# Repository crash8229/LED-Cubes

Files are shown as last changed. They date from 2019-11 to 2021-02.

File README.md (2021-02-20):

# LED-Cubes
A repo to hold my LED cube related projects.

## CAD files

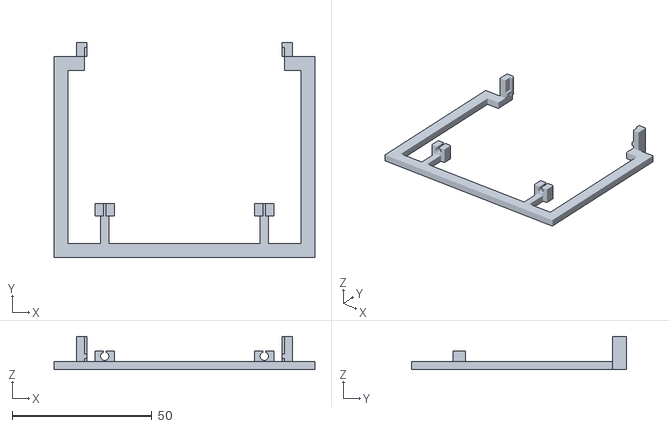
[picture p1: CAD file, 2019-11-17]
LED_Matrix_Jigs/LED_Matrix_Full_Assembly_Jig_Part_2_of_4.stl
93.5 x 77.0 x 12.0

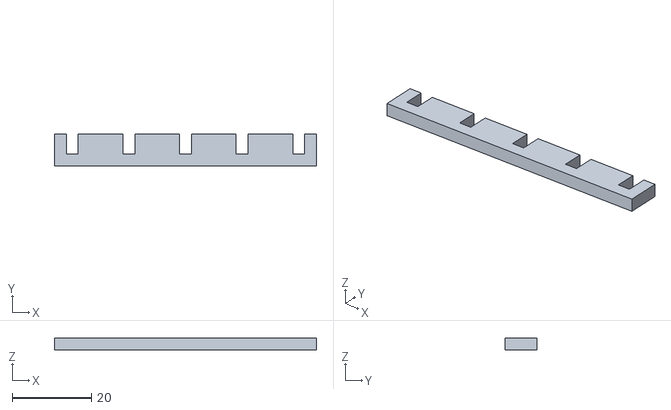
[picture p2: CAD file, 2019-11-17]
LED_Matrix_Jigs/LED_Matrix_Full_Assembly_Jig_Part_4_of_4.stl
66.2 x 8.00 x 3.00

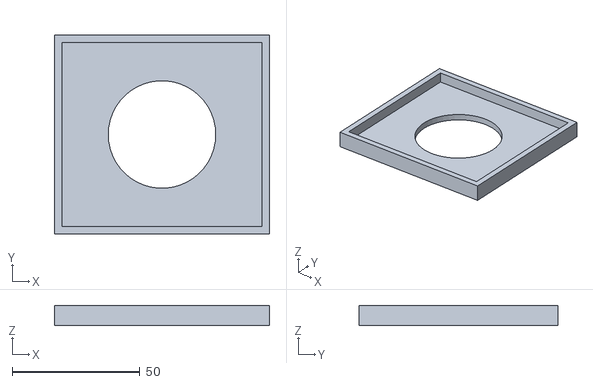
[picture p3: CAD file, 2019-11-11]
LED_Matrix_Jigs/LED_Matrix_Full_Assembly_Jig_Part_3_of_4.stl
84.0 x 77.7 x 8.00

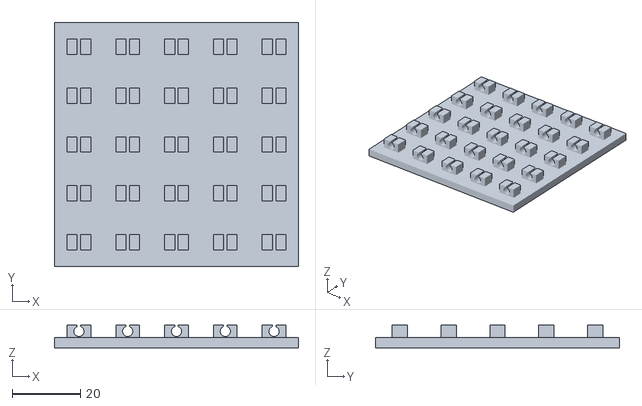
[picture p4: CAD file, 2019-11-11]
LED_Matrix_Jigs/LED_Matrix_Vertical_Slice_Assembly_Jig.stl
71.5 x 71.5 x 6.70

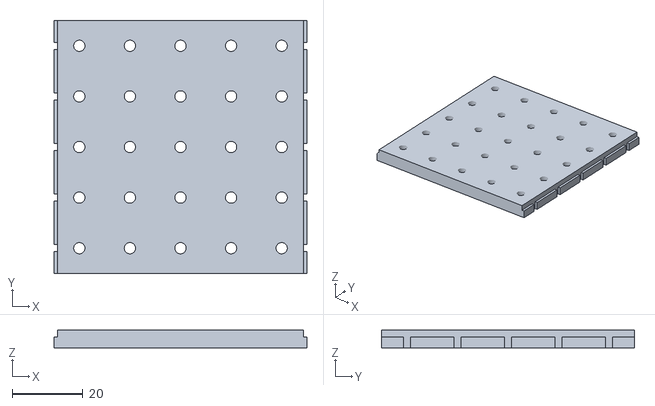
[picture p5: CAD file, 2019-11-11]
LED_Matrix_Jigs/LED_Matrix_Full_Assembly_Jig_Part_1_of_4.stl
71.5 x 71.5 x 5.00

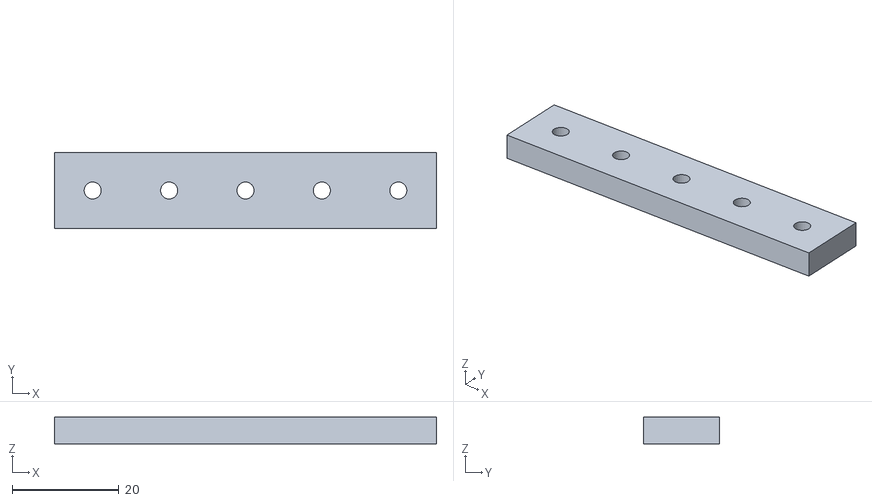
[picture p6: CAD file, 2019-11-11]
LED_Matrix_Jigs/LED_Matrix_Row_Assembly_Jig.stl
71.5 x 14.3 x 5.00

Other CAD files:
LED_Matrix_Jigs/LED_Matrix_Assembly_Jigs.FCStd

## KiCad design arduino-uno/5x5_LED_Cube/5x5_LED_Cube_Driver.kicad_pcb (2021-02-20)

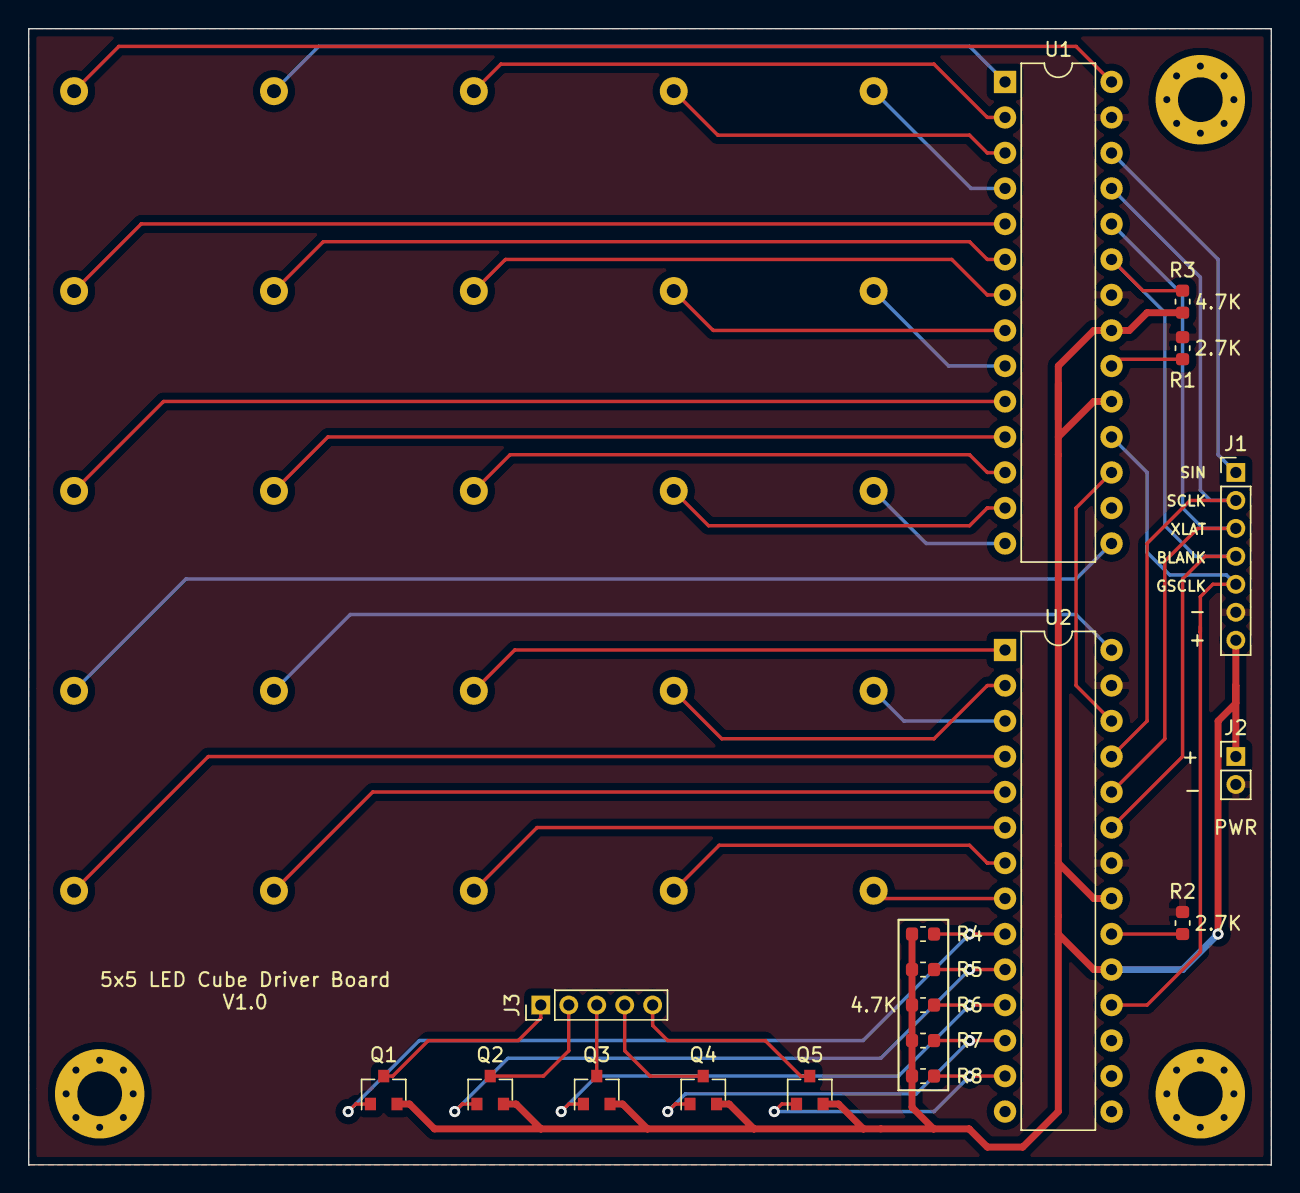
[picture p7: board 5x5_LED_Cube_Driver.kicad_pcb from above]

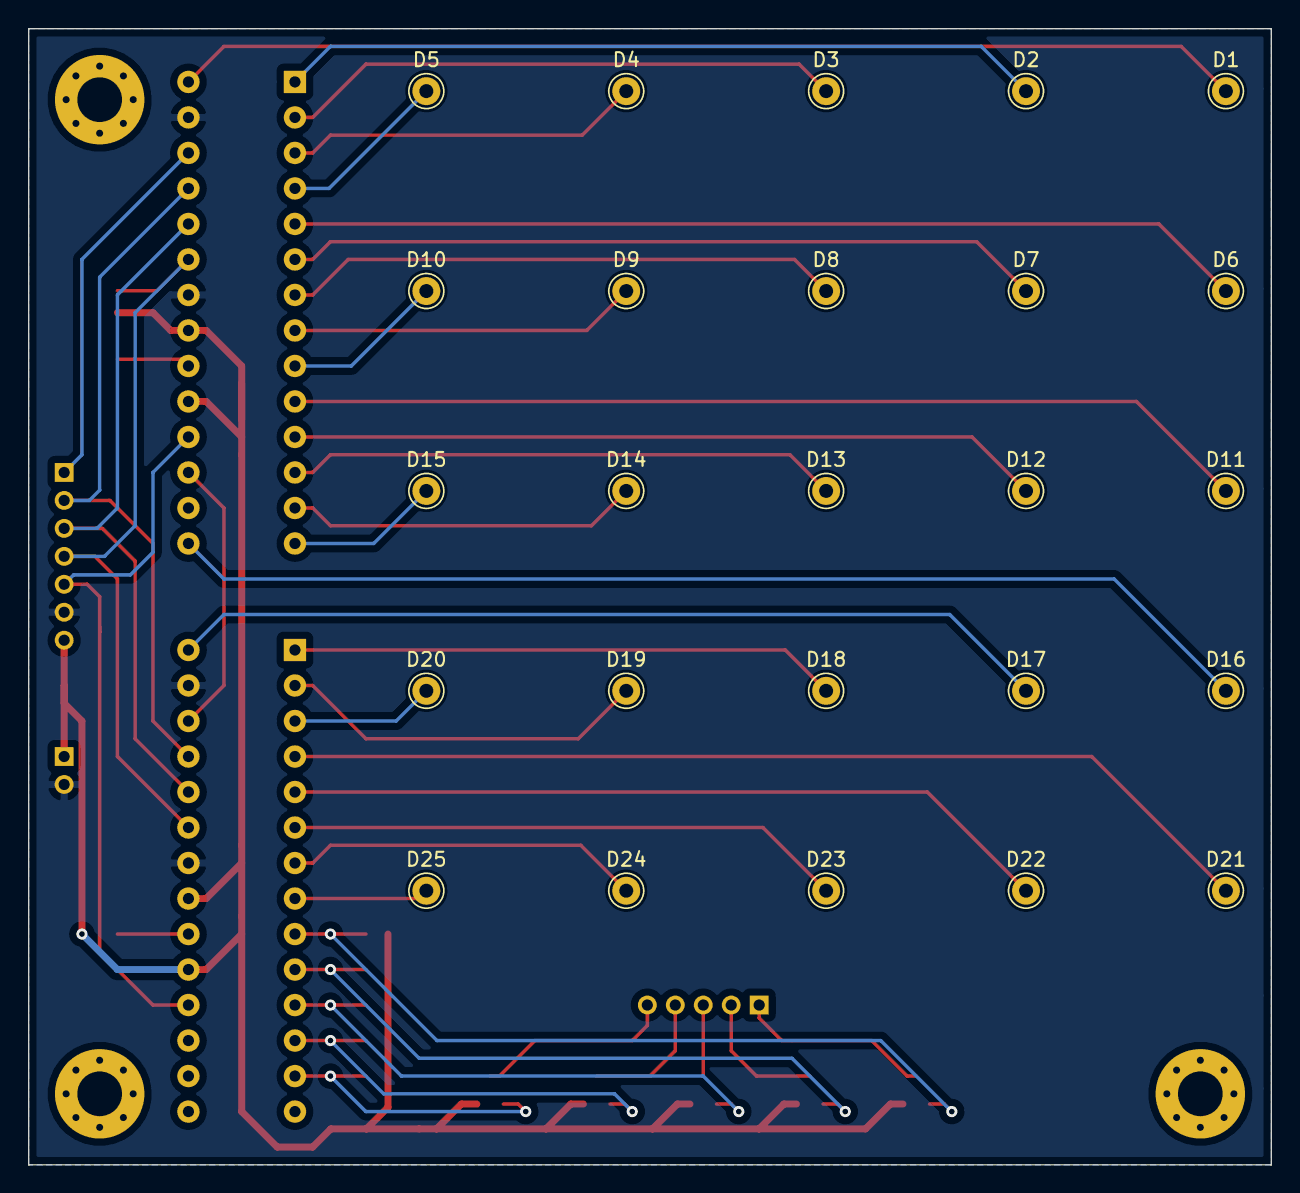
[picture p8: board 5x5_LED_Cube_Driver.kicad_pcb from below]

Board: 2 copper layers, 88.9 x 81.3 mm, 43 parts (25 on the bottom side), 45 nets.

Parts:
D1, D2, D3, D4, D5, D6, D7, D8, D9, D10, D11, D12, D13, D14, D15, D16, D17, D18, D19, D20, D21, D22, D23, D24, D25: LED; Pin_D1.0mm_L10.0mm
J1: Arduino; PinHeader_1x07_P2.00mm_Vertical
J2: Power; PinHeader_1x02_P2.00mm_Vertical
J3: Layers; PinHeader_1x05_P2.00mm_Vertical
Q1, Q2, Q3, Q4, Q5: DMG2305UX; SOT-23
R1, R2: 2.7K; R_0603_1608Metric
R3, R4, R5, R6, R7, R8: 4.7K; R_0603_1608Metric
U1, U2: TLC5940NT; DIP-28_W7.62mm

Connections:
+5V: J1.7, J2.1, Q1.2, Q2.2, Q3.2, Q4.2, Q5.2, R3.2, R4.1, R5.1, R6.1, R7.1, R8.1, U1.19, U1.21, U2.19, U2.21
/ArduinoD3(GSCLK): J1.5, U1.18, U2.18
/ArduinoD9(XLAT): J1.3, U1.24, U2.24
/ArduinoD10(BLANK): J1.4, R3.1, U1.23, U2.23
/ArduinoD11(SIN): J1.1, U1.26
/ArduinoD13(SCLK): J1.2, U1.25, U2.25
/IREF1: R1.1, U1.20
/IREF2: R2.1, U2.20
/LED1: D1.1, U1.28
/LED2: D2.1, U1.1
/LED3: D3.1, U1.2
/LED4: D4.1, U1.3
/LED5: D5.1, U1.4
/LED6: D6.1, U1.5
/LED7: D7.1, U1.6
/LED8: D8.1, U1.7
/LED9: D9.1, U1.8
/LED10: D10.1, U1.9
/LED11: D11.1, U1.10
/LED12: D12.1, U1.11
/LED13: D13.1, U1.12
/LED14: D14.1, U1.13
/LED15: D15.1, U1.14
/LED16: D16.1, U1.15
/LED17: D17.1, U2.28
/LED18: D18.1, U2.1
/LED19: D19.1, U2.2
/LED20: D20.1, U2.3
/LED21: D21.1, U2.4
/LED22: D22.1, U2.5
/LED23: D23.1, U2.6
/LED24: D24.1, U2.7
/LED25: D25.1, U2.8
/Layer1: J3.1, Q1.3
/Layer1Gate: Q1.1, R4.2, U2.9
/Layer2: J3.2, Q2.3
/Layer2Gate: Q2.1, R5.2, U2.10
/Layer3: J3.3, Q3.3
/Layer3Gate: Q3.1, R6.2, U2.11
/Layer4: J3.4, Q4.3
/Layer4Gate: Q4.1, R7.2, U2.12
/Layer5: J3.5, Q5.3
/Layer5Gate: Q5.1, R8.2, U2.13
/SOUT1: U1.17, U2.26
GND: J1.6, J2.2, R1.2, R2.2, U1.22, U1.27, U2.22, U2.27

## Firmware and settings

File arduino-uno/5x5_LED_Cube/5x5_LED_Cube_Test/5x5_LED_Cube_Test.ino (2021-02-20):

/*
    Basic Pin setup:
    ------------                                  ---u----
    ARDUINO   13|-> SCLK (pin 25)           OUT1 |1     28| OUT channel 0
              12|                           OUT2 |2     27|-> GND (VPRG)
              11|-> SIN (pin 26)            OUT3 |3     26|-> SIN (pin 11)
              10|-> BLANK (pin 23)          OUT4 |4     25|-> SCLK (pin 13)
               9|-> XLAT (pin 24)             .  |5     24|-> XLAT (pin 9)
               8|                             .  |6     23|-> BLANK (pin 10)
               7|                             .  |7     22|-> GND
               6|                             .  |8     21|-> VCC (+5V)
               5|                             .  |9     20|-> 2K Resistor -> GND
               4|                             .  |10    19|-> +5V (DCPRG)
               3|-> GSCLK (pin 18)            .  |11    18|-> GSCLK (pin 3)
               2|                             .  |12    17|-> SOUT
               1|                             .  |13    16|-> XERR
               0|                           OUT14|14    15| OUT channel 15
    ------------                                  --------

    -  Put the longer leg (anode) of the LEDs in the +5V and the shorter leg
         (cathode) in OUT(0-15).
    -  +5V from Arduino -> TLC pin 21 and 19     (VCC and DCPRG)
    -  GND from Arduino -> TLC pin 22 and 27     (GND and VPRG)
    -  digital 3        -> TLC pin 18            (GSCLK)
    -  digital 9        -> TLC pin 24            (XLAT)
    -  digital 10       -> TLC pin 23            (BLANK)
    -  digital 11       -> TLC pin 26            (SIN)
    -  digital 13       -> TLC pin 25            (SCLK)
    -  The 2K resistor between TLC pin 20 and GND will let ~20mA through each
       LED.  To be precise, it's I = 39.06 / R (in ohms).  This doesn't depend
       on the LED driving voltage.
    - (Optional): put a pull-up resistor (~10k) between +5V and BLANK so that
                  all the LEDs will turn off when the Arduino is reset.

    If you are daisy-chaining more than one TLC, connect the SOUT of the first
    TLC to the SIN of the next.  All the other pins should just be connected
    together:
        BLANK on Arduino -> BLANK of TLC1 -> BLANK of TLC2 -> ...
        XLAT on Arduino  -> XLAT of TLC1  -> XLAT of TLC2  -> ...
    The one exception is that each TLC needs it's own resistor between pin 20
    and GND.

    This library uses the PWM output ability of digital pins 3, 9, 10, and 11.
    Do not use analogWrite(...) on these pins.

    This sketch does the Knight Rider strobe across a line of LEDs.

    Alex Leone <acleone ~AT~ gmail.com>, 2009-02-03 */

#include "SparkFun_Tlc5940.h"
#include <inttypes.h>

//uint32_t data = 0x3FFFFFFF;
int layer = 0;

void setup()
{
  /* Call Tlc.init() to setup the tlc.
     You can optionally pass an initial PWM value (0 - 4095) for all channels.*/
  Tlc.init();
  delay(200);
}

/* This loop will create a Knight Rider-like effect if you have LEDs plugged
   into all the TLC outputs.  NUM_TLCS is defined in "tlc_config.h" in the
   library folder.  After editing tlc_config.h for your setup, delete the
   Tlc5940.o file to save the changes. */

void loop()
{
//  Tlc.clear();
//  Tlc.set(0, 2000);
//  Tlc.set(27, 2000);
//  Tlc.update();
  layerTest();
  ledTest();
  
}

void layerTest(){
  while (layer < 5){
    Tlc.clear();
    for (int led = 0; led < 25; led++){
      Tlc.set(led, 4095);
    }
    Tlc.set(25+layer, 4095);
    Tlc.update();
    layer++;
    delay(200);
  }
  layer = 0;
}

void ledTest()
{
  while (layer < 5){
    for (int led = 0; led < 25; led++){
      Tlc.clear();
      Tlc.set(led, 4095);
      Tlc.set(25+layer, 4095);
      Tlc.update();
      delay(100);
    }
    layer++;
  }
  layer = 0;
}

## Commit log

2019-11-03 Added TLC5940 resistance calculation for IREF
    [TLC5940_IREF.xlsx]
2019-11-04 Completed schematic for the 5x5 LED Cube
    [5x5_LED_Cube.kicad_pcb, 5x5_LED_Cube_Controller.sch, 5x5_LED_Cube_Matrix.sch]
2019-11-04 Started on pcb for 5x5 LED Cube
    [5x5_LED_Cube.kicad_pcb, 5x5_LED_Cube_Controller.kicad_pcb, 5x5_LED_Cube_Controller.sch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]
2019-11-06 Added custom library to hold custom componets and removed unused .pro file
    [5x5_LED_Cube_Controller.sch]
2019-11-07 Added headers for layers and arduino input
    [5x5_LED_Cube_Controller.kicad_pcb, 5x5_LED_Cube_Controller.sch, 5x5_LED_Cube_Matrix.sch]
2019-11-07 Updated PCB to latest schematic changes
    [5x5_LED_Cube_Controller.kicad_pcb]
2019-11-08 Routed more PCB traces and added power header
    [5x5_LED_Cube_Controller.kicad_pcb, 5x5_LED_Cube_Controller.sch, 5x5_LED_Cube_Matrix.sch]
2019-11-11 Created jigs to help with assembly
    [LED_Matrix_Assembly_Jigs.FCStd, LED_Matrix_Full_Assembly_Jig_Part_1_of_2.stl, LED_Matrix_Full_Assembly_Jig_Part_2_of_2.stl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]
2019-11-11 Added retaining ring to full jig
    [LED_Matrix_Assembly_Jigs.FCStd, LED_Matrix_Full_Assembly_Jig_Part_1_of_3.stl, LED_Matrix_Full_Assembly_Jig_Part_2_of_3.stl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]
2019-11-11 Finished PCB routing
    [5x5_LED_Cube_Controller.kicad_pcb]
2019-11-12 Removed traces and rearannged footprints a little
    [5x5_LED_Cube_Controller.kicad_pcb]
2019-11-13 Added traces for Arduino side
    [5x5_LED_Cube_Controller.kicad_pcb]
2019-11-14 Fixed the jigs again and add a spacer
    [LED_Matrix_Assembly_Jigs.FCStd, LED_Matrix_Full_Assembly_Jig_Part_1_of_4.stl, LED_Matrix_Full_Assembly_Jig_Part_2_of_3.stl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]
2019-11-15 PCB shrunken to the max
    [5x5_LED_Cube_Controller.kicad_pcb, 5x5_LED_Cube_Controller.sch]
2019-11-15 Finished PCB
    [5x5_LED_Cube_Controller.kicad_pcb, 5x5_LED_Cube_Controller.sch]
2019-11-15 5x5 LED Cube: Renamed project files
    [5x5_LED_Cube_Driver.kicad_pcb, 5x5_LED_Cube_Driver.sch]
2019-11-17 Simple test program for the 5x5 LED cube
2019-11-17 Replaced the SIP resistor with SMD ones
    [5x5_LED_Cube_Driver.kicad_pcb, 5x5_LED_Cube_Driver.sch, 5x5_LED_Cube_Matrix.sch]
2019-11-18 Grouped the PCB traces for layers closer together
    [5x5_LED_Cube_Driver.kicad_pcb]
2019-11-23 Fixed the headers being too small for the wires
    [5x5_LED_Cube_Driver.kicad_pcb, 5x5_LED_Cube_Driver.sch, 5x5_LED_Cube_Matrix.sch]
2021-02-20 Push gdrive files to consolidate them
    [5x5_LED_Cube_Driver.kicad_pcb, 5x5_LED_Cube_Driver.sch, 5x5_LED_Cube_Matrix.sch]
